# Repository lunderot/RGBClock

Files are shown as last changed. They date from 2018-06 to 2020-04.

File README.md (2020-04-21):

A clock with wifi connectivity and a RGB display.  

The clock uses an esp8266 as the main processor with ws2812 LEDs for the display.  
The front face is 3d printed in PLA.  

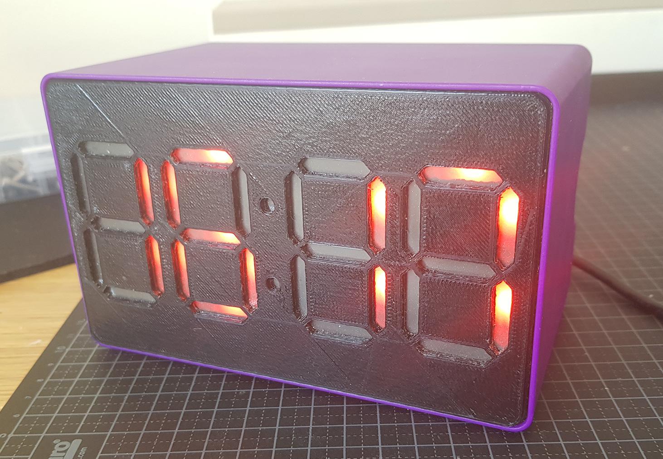
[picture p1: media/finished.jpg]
Finished clock
[](https://raw.githubusercontent.com/lunderot/RGBClock/master/media/finished.jpg)
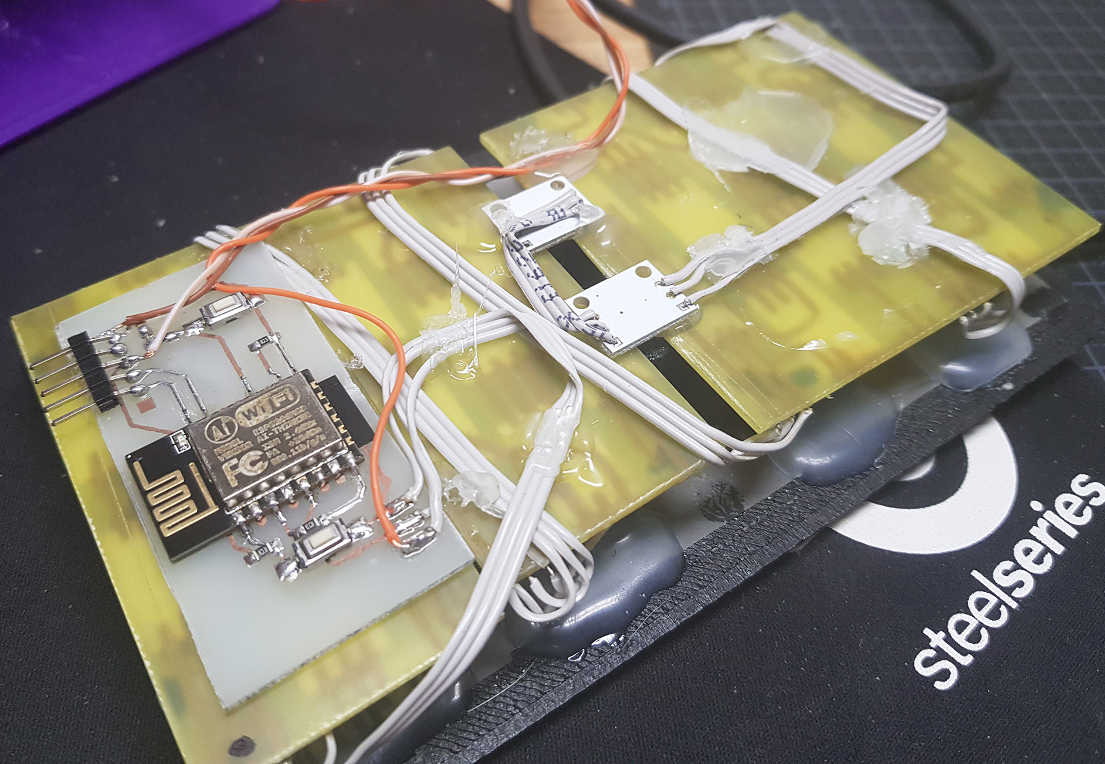
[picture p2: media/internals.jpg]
Internals of the clock
[](https://raw.githubusercontent.com/lunderot/RGBClock/master/media/internals.jpg)

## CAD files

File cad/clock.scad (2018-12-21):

module segment()
{
	minkowski()
	{
		polygon([[0,0],[4,4],[32,4],[36,0],[32,-4],[4,-4]]);
		circle(r=.5, $fn=100);
	}
}

module digit()
{
	list = [
		[0,0,0],
		[0,-40,0],
		[0,-80,0],
		[2,-2,-90],
		[42,-2,-90],
		[42,38,-90],
		[2,38,-90]
	];

	for (i=list)
	{
		rotate(i[2])
		translate([i[0], i[1]])
		segment();
	}
}

module display()
{
	list = [0,56,124,180];

	scale(.61864)
	translate([-108,40])
	union()
	{
		for (i=list)
		{
			translate([i, 0])
			digit();
		}

		translate([108,-20])
		circle(r=4);
		translate([108,-60])
		circle(r=4);
	}
}

module face()
{
	d = [151,91];
	radius = 5;
	hull()
	for(i=[[0,0], [0,1], [1,0], [1,1]])
		mirror([0,i[1]])
		mirror([i[0],0])
		translate([d[0]/2-radius,d[1]/2-radius])
		circle(r=radius,$fn=100);
}

$fn = 100;

translate([0, 0, 2])
linear_extrude(10)
difference()
{
	minkowski()
	{
		hull()
		display();
		square(size=[5, 5], center=true);
	}
	display();
}


linear_extrude(2)
difference()
{
	face();
	display();
}

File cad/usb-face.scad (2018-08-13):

$fn = 50;

bottom = 5;
top = 3;


difference()
{
	union()
	{
		translate([0,0,bottom])
		linear_extrude(top)
		hull()
		{
			circle(r=6);
			translate([8, 0, 0])
			circle(r=6);
		}
		linear_extrude(bottom)
		translate([4, 0])
		square([34, 14], center=true);
	}

	linear_extrude(bottom+top+1)
	translate([4, 0])
	scale(1.01)
	square([12, 11], center=true);

	
	translate([4, 0, bottom])
	linear_extrude(top)
	scale(1.01)
	square([12, 13], center=true);
}

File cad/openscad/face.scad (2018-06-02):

use <numbers-old.scad>
use <rounded-corners-old.scad>

//square([151, 91], center=true);

scale(1.25)
{
	translate([0, 0, 2])
	{
		linear_extrude(10)
		{
			difference()
			{
				minkowski()
				{
					circle(2.1);
					all_numbers();
				}
				minkowski()
				{
					circle(0.2);
					all_numbers();
				}
			}
		}
	}

	////Front plate with holes
	//linear_extrude(2)
	//difference()
	//{
	//	rounded_corners();
	//	all_numbers();
	//}
}

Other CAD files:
cad/openscad/numbers.scad
cad/old/numbers-old.scad
cad/old/numbers.scad
cad/old/rounded-corners-old.scad
cad/old/rounded-corners.scad
cad/openscad/rounded-corners.scad

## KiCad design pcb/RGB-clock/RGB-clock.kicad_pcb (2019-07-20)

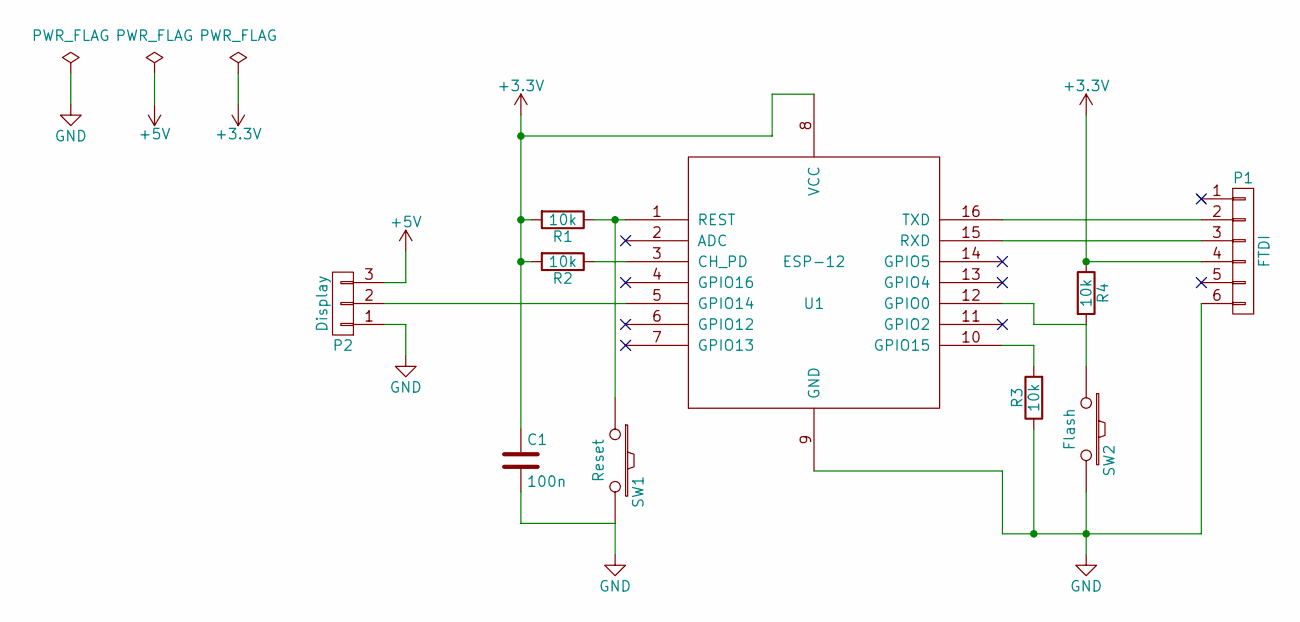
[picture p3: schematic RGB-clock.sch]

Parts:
C1: 100n; C_0805_HandSoldering
P1: FTDI; Pin_Header_Straight_1x06_Pitch2.54mm
P2: Display; Pin_Header_Straight_1x03_Pitch2.54mm
R1, R2, R3, R4: 10k; R_0805_HandSoldering
SW1: Reset; SW_SPST_REED_CT05-XXXX-G1
SW2: Flash; SW_SPST_REED_CT05-XXXX-G1
U1: ESP-12

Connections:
+3V3: C1.1, P1.4, R1.2, R2.2, R4.1, U1.8 (VCC)
+5V: P2.3
GND: C1.2, P1.6, P2.1, R3.1, SW1.2, SW2.2, U1.9 (GND)
unnamed: P1.2, U1.16 (TXD)
unnamed: P1.3, U1.15 (RXD)
unnamed: P2.2, U1.5 (GPIO14)
unnamed: R1.1, SW1.1, U1.1 (REST)
unnamed: R2.1, U1.3 (CH_PD)
unnamed: R3.2, U1.10 (GPIO15)
unnamed: R4.2, SW2.1, U1.12 (GPIO0)

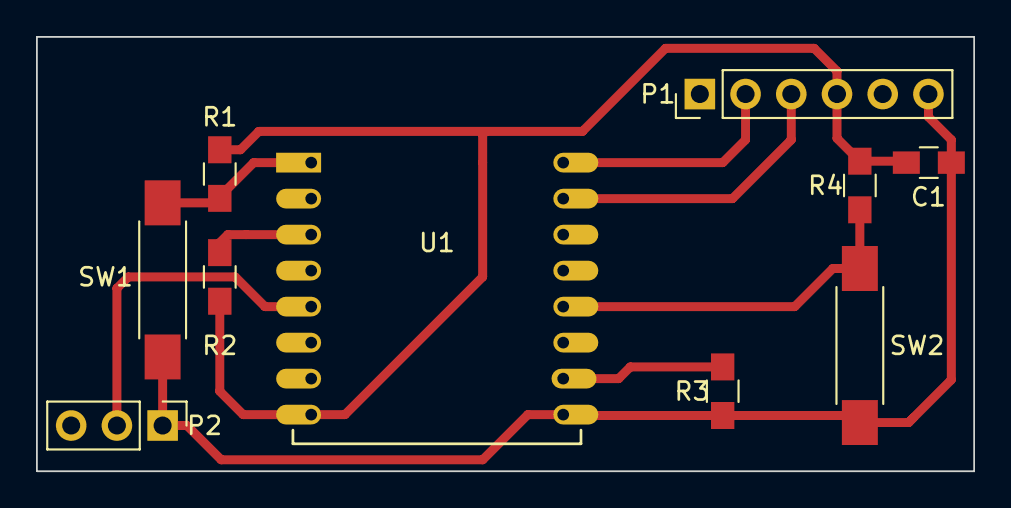
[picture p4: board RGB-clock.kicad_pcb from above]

Board: 2 copper layers, 52.1 x 24.1 mm, 10 parts (0 on the bottom side), 9 nets.

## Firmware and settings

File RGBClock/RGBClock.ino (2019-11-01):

#include <ESP8266WiFi.h>
#include <WiFiClientSecure.h>
#include <Adafruit_NeoPixel.h>
#include <time.h>

#include "user.h"
#include "digitmap.h"

#define DEBUG

#ifdef DEBUG
#define DPRINT_SETUP(...)          \
	do                             \
	{                              \
		Serial.begin(__VA_ARGS__); \
	} while (0)
#define DPRINT(...)                \
	do                             \
	{                              \
		Serial.print(__VA_ARGS__); \
		Serial.flush();            \
	} while (0)
#define DPRINTLN(...)                \
	do                               \
	{                                \
		Serial.println(__VA_ARGS__); \
		Serial.flush();              \
	} while (0)
#else
#define DPRINT_SETUP(...)
#define DPRINT(...)
#define DPRINTLN(...)
#endif

const char *host = "script.google.com";
const char *host2 = "script.googleusercontent.com";
const int port = 443;

const char *httpGET = "GET %s HTTP/1.1\r\n"
					  "Host: %s\r\n"
					  "Connection: close\r\n"
					  "\r\n";

const int pixelPin = 14;

time_t currentTime = 1;
time_t alarm = 0;

Adafruit_NeoPixel strip = Adafruit_NeoPixel(7 * 4 + 2, pixelPin, NEO_GRB + NEO_KHZ800);
char redirect_path[300] = {0};

void connectToWifi()
{
	DPRINTLN();
	DPRINT("Connecting to wifi: ");
	DPRINTLN(ssid);

	WiFi.begin(ssid, password);
	while (WiFi.status() != WL_CONNECTED)
	{
		delay(500);
		DPRINT(".");
	}

	DPRINTLN("");
	DPRINTLN("WiFi connected");
	DPRINT("IP address: ");
	DPRINTLN(WiFi.localIP());
}

int find_redirect_path(const char *data, void *redirect_path)
{
	int returnValue = 0;
	char *str = strstr(data, host2);
	if (str)
	{
		DPRINT("Found redirect: ");
		memset((char *)redirect_path, 0, 300);
		strcpy((char *)redirect_path, str + strlen(host2));
		DPRINTLN((char*)redirect_path);
		returnValue = 1;
	}
	return returnValue;
}

int get_time(const char *data, void *user_data)
{
	int httpCode = 0;
	int read = sscanf(data, "HTTP/1.1 %u %*s", &httpCode);
	if (read && httpCode != 200)
		return 1;

	read = sscanf(data, "|%lu %lu", &currentTime, &alarm);
	if (read)
	{
		DPRINT("CurrentTime: ");
		DPRINTLN(currentTime);
		DPRINT("Alarm: ");
		DPRINTLN(alarm);
	}
	return 0;
}

//If callback returns 1, the connection is closed
int makeRequest(const char *host, int port, const char *url, int (*callback)(const char *, void *), void *user_data)
{
	WiFiClientSecure client;
	int stop = 0;
	char buf[512] = {0};
	char request[400] = {0};
	int success = 0;

	sprintf(request, httpGET, url, host);

	if (client.connect(host, port))
	{
		client.print(request);
		while (client.connected() && !stop)
		{
			int available = client.available();
			if (available)
			{
				memset(buf, 0, 512);
				client.readBytesUntil('\n', buf, 512);
				stop = callback(buf, user_data);
			}
			delay(available == 0 ? 300 : 10);
		}
		client.stop();
		success = 1;
	}
	else
	{
		DPRINTLN("Failed to connect to: ");
		DPRINTLN(host);
		client.stop();
		success = 0;
	}
	return success;
}

void updateTime()
{
	while (!makeRequest(host, port, gscript, find_redirect_path, redirect_path))
		;
	while (!makeRequest(host2, port, redirect_path, get_time, NULL))
		;
}

void secondTick(void)
{
	timer0_write(ESP.getCycleCount() + 80000000L); // 80MHz == 1sec

	currentTime++;
	struct tm *timeData = gmtime(&currentTime);

	uint32_t color = strip.Color(255, 0, 0);
	uint32_t off = strip.Color(0, 0, 0);

	char disp[5] = {0};

	sprintf(disp, "%.2d%.2d", timeData->tm_hour, timeData->tm_min);
	displayNumber(disp, color, off);

	uint32_t digitColor = timeData->tm_sec % 2 ? color : off;
	strip.setPixelColor(7 * 4 + 0, digitColor);
	strip.setPixelColor(7 * 4 + 1, digitColor);

	strip.show();
}

void setup()
{
	DPRINT_SETUP(9600);

	strip.begin();

	noInterrupts();
	timer0_isr_init();
	timer0_attachInterrupt(secondTick);
	timer0_write(ESP.getCycleCount() + 80000000L);
	interrupts();

	connectToWifi();
	updateTime();
}

void displayDigit(int number, int offset, uint32_t color, uint32_t off)
{
	number %= 10;
	for (int i = 0; i < 7; i++)
	{
		char result = ((digitmap[number] << i) & 0b10000000) == 0b10000000;
		strip.setPixelColor(i + offset, result ? color : off);
	}
}

void displayNumber(char *num, uint32_t color, uint32_t off)
{
	for (int i = 0; i < 4; i++)
	{
		displayDigit(num[i] - '0', i * 7, color, off);
	}
}

void loop()
{
	if (!(currentTime % 2048))
	{
		updateTime();
	}
	delay(500);
}

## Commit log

2018-06-02 Initial commit
    Added CAD files
    Added basic esp program with a HTTP request
    [face.scad, numbers-old.scad, numbers.scad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]
2018-06-06 Now the program stores the current time and can display numbers
2018-08-13 Added USB connector model
    [usb-face.scad]
2018-08-15 Added PCB design
    [RGB-clock.kicad_pcb, RGB-clock.sch]
2018-12-21 Reamade model in pure OpenSCAD
    [clock.scad, face.scad, numbers-old.scad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]
2019-07-20 Updated PCB
    [RGB-clock-2019-07-13-17-03-34.sch, RGB-clock.kicad_pcb, RGB-clock.sch]
